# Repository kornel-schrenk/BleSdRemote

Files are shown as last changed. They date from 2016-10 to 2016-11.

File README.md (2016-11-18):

# BleSdRemote

For more information please see this blog [post](http://www.schrenk.hu/2016/11/17/BleSdRemote/)!

## Description

Nowadays some high end phones do not have an extra SD card slot, therefore its users are limited to the  internal storage space of the device. If you need more, you have to spend more money or use the manufacturer's proprietary cloud solution as an alternative extension.

Is there a way to solve this problem? I hope so! Only some *extra* storage space has to be *attached* to these mobile phones.

However this attachment can be problematic! Fortunately [Bluetooth Low Energy](https://en.wikipedia.org/wiki/Bluetooth_low_energy) (BLE) is supported by today's all major mobile phone operating systems: iOS, Android and Windows Phone. The idea is to add extra storage space to these mobile phones through BLE, which *demonstrates* that this extension is **possible**!

The solution consist of two parts:
1. An external SD card extension, which is driven by an [Arduino](http://www.arduino.org/) microcontroller.
2. An [Android](https://www.android.com/) application, which provides access to the remote SD card content.

The repository contains the [Arduino](http://www.arduino.org/) code. The related [Android](https://www.android.com/) code can be found in the [BleSdRemoteDroid](https://github.com/kornel-schrenk/BleSdRemoteDroid) GitHub repository.

## Breadboard view

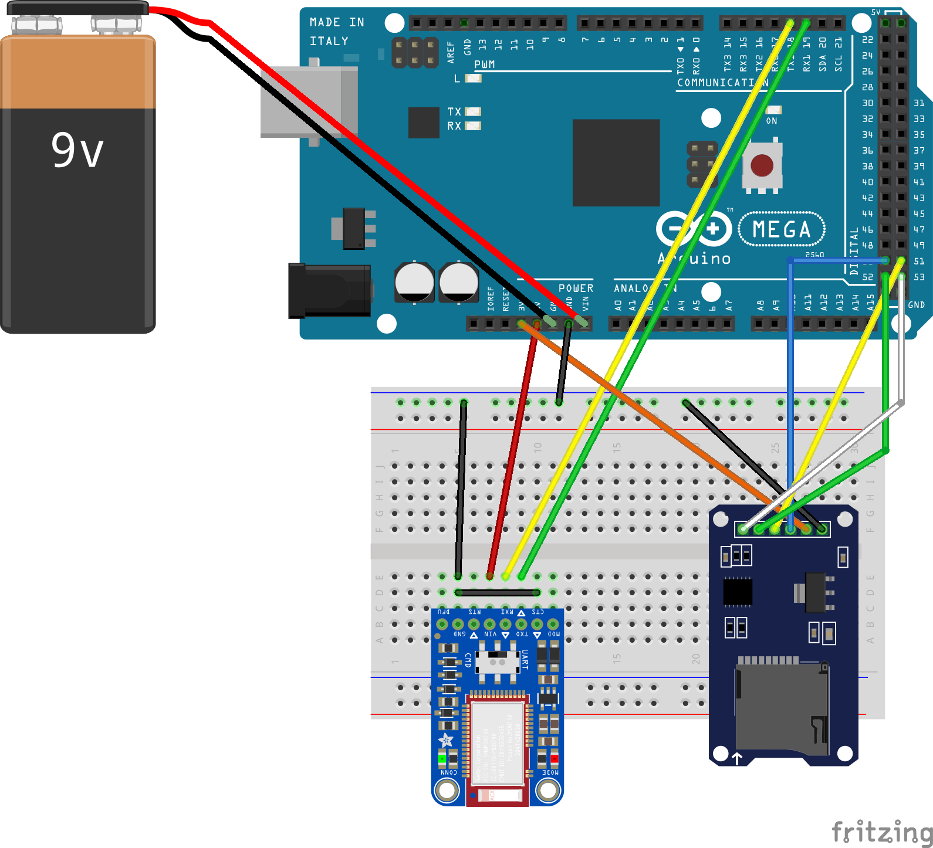
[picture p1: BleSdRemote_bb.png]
Fritzing breadboard view


## Communication API

```javascript
IN  <-: @LIST# - List all files and directories in the root folder
OUT ->: @DIVE0001.TXT,DIVE0002.TXT,DIVE0003.TXT,LOGBOOK.TXT,BOOKS/,PICTURES/,#

IN  <-: @LIST:BOOKS# - List all files and directories in the given folder
OUT ->: @../,TEST.JPG,TUSKEVAR.PDF,BAROK.PDF,#

IN  <-: @INFO:Images/About.png# - Sends back information about the given file
OUT ->: @<file name>%<file size in bytes>%<file creation date>%<file modification date>#

IN  <-: @DELF:Images/About.png# - Deletes the given file on the SD card
OUT ->: @OK%<file path># or @KO%<file path>#

IN  <-: @GETF:Images/About.png# - Download the given file from the SD card
OUT ->: @<file size in bytes>#<file content>

IN  <-: @PUTF:Images/About.png%<file size in bytes># - Upload the given file to the SD card
OUT ->: @OK# -> Switch Arduino into file receiving mode
IN  <-: <file content>
```

Every inbound message starts with the **@** character and ends with a **#**. The **:** divides the message into two parts; the keyword and the payload part. Outbound messages are similar to the inbound messages except that the delimiter character is the **%**.

## Repository Owner 

* [Kornel Schrenk](http://www.schrenk.hu/about/)

## License

This software is available under [MIT](../master/LICENSE) license.

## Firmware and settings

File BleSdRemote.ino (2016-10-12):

#include "Arduino.h"
#include "SPI.h"
#include "SdFat.h"

#include "Adafruit_BLE.h"
#include "Adafruit_BluefruitLE_SPI.h"
#include "Adafruit_BluefruitLE_UART.h"

#include "BluefruitConfig.h"

//Please set it to 1, if factory reset is desired during startup otherwise set it to 0
#define FACTORYRESET_ENABLE 0

#if defined(HAVE_HWSERIAL1) //Use the first physical serial UART on Arduino Mega or Due
Adafruit_BluefruitLE_UART ble(Serial1, BLUEFRUIT_UART_MODE_PIN);
#else //Use Software Serial interface -- Do not forget to adjust the configuration!!!
SoftwareSerial bluefruitSS = SoftwareSerial(BLUEFRUIT_SWUART_TXD_PIN, BLUEFRUIT_SWUART_RXD_PIN);
Adafruit_BluefruitLE_UART ble(bluefruitSS, BLUEFRUIT_UART_MODE_PIN, BLUEFRUIT_UART_CTS_PIN, BLUEFRUIT_UART_RTS_PIN);
#endif

const int ledPin = 13;  // led pin
const int sdChipSelectPin = 53; //For Mega TFT LCD shield use 53, for SD card reader use 10

SdFat SD;

//Message handling related variables 
String messageBuffer = "";
bool recordMessage = false;

bool storeInFileMode = false;
unsigned long storeFileSize = 0;
unsigned long receivedFileSize = 0;
SdFile storeFile;

void setup() {
	Serial.begin(115200);

	while (!Serial) { // Wait for USB Serial
		SysCall::yield();
	}
	delay(1000);

	Serial.println(F("\nBlueSdRemote - START\n"));

	Serial.print(F("SD - Initializing SD card..."));
	pinMode(sdChipSelectPin, OUTPUT);
	if (!SD.begin(sdChipSelectPin, SPI_HALF_SPEED)) {
		//Stop the sketch execution
		SD.initErrorHalt();
	} else {
		Serial.println(F(" Done."));
	}

	/* Initialise the module */
	Serial.print(F("BLE - Initializing the Bluefruit LE module: "));

	if (!ble.begin(VERBOSE_MODE)) {
		Serial.println(F("Couldn't find Bluefruit, make sure it's in CoMmanD mode & check wiring?"));
	}
	Serial.println(F("OK!"));

	if (FACTORYRESET_ENABLE) {
		/* Perform a factory reset to make sure everything is in a known state */
		Serial.println(F("BLE - Performing a factory reset: "));
		if (!ble.factoryReset()) {
			Serial.println(F("Couldn't do factory reset"));
		} else {
			Serial.println(F("OK!"));
		}
	}

	ble.echo(false);
	ble.info();
	ble.verbose(false);

	/* Wait for connection - Adafruit Bluefruit LE app has to be used to establish an UART connection. */
	while (!ble.isConnected()) {
		delay(500);
	}

	// Set module to DATA mode
	ble.setMode(BLUEFRUIT_MODE_DATA);
	Serial.println(F("BLE - Switched to DATA mode!"));
}

void loop() {

	//Read messages from the standard Serial interface
	if (Serial.available() > 0) {
		readMessageFromSerial(Serial.read());
	}

	//Read messages from the BLE interface
	while (ble.available()) {
		readMessageFromSerial((char) ble.read());
	}
}

void readMessageFromSerial(char data) {
	if (!storeInFileMode) {
		if (data == '@') {
			messageBuffer = "";
			recordMessage = true;
			digitalWrite(ledPin, HIGH); //Turn the LED on
		} else if (data == '#') {
			handleMessage(messageBuffer);
			recordMessage = false;
			digitalWrite(ledPin, LOW); //Turn the LED off
		} else {
			if (recordMessage) {
				messageBuffer += data;
			}
		}
	} else {
		if (receivedFileSize < storeFileSize && storeFile.isOpen()) {
			storeFile.write(data);
			receivedFileSize++;
		} else if (receivedFileSize == storeFileSize) {
			storeFile.flush();
			storeFile.close();

			Serial.print(receivedFileSize);
			Serial.print("/");
			Serial.println(storeFileSize);
			Serial.flush();

			Serial.println(F("Switched back into normal message processing mode!"));

			messageBuffer = "";
			storeInFileMode = false;
		}

		if (receivedFileSize % 512 == 0) {
			storeFile.flush();

			Serial.print(receivedFileSize);
			Serial.print("/");
			Serial.println(storeFileSize);
			Serial.flush();
		}
	}
}

void handleMessage(String message) {
	Serial.println(message);
	Serial.flush();

	String responseMessage = "";
	if (message.startsWith(F("LIST:")) || message.startsWith(F("list:"))) {

		//The String has to be converted into a char array, otherwise the board will reset itself
		String directoryPath = extractDirectoryPath(message);
		char directoryPathArray[directoryPath.length()+1];
		directoryPath.toCharArray(directoryPathArray, directoryPath.length()+1);

		if (SD.chdir(directoryPathArray)) {
			responseMessage += listDirectory(SD.vwd(), false);
			SD.chdir(); //Change back to the ROOT directory
		} else {
			Serial.print(F("Failed to open "));
			Serial.println(directoryPathArray);
			responseMessage += F("ERROR");
		}
		Serial.println(responseMessage);
		Serial.flush();
		ble.print(responseMessage);
		ble.flush();
	} else if (message.startsWith(F("LIST")) || message.startsWith(F("list"))) {
		//Change back to the ROOT directory
		if (SD.chdir()) {
			responseMessage += listDirectory(SD.vwd(), true);
		} else {
			responseMessage += F("ERROR");
		}
		Serial.println(responseMessage);
		Serial.flush();
		ble.print(responseMessage);
		ble.flush();
	} else if (message.startsWith(F("INFO:")) || message.startsWith(F("info:"))) {

		//The String has to be converted into a char array, otherwise the board will reset itself
		String directoryPath = extractDirectoryPath(message);
		char directoryPathArray[directoryPath.length()+1];
		directoryPath.toCharArray(directoryPathArray, directoryPath.length()+1);

		SdFile currentFile;
		if (currentFile.open(directoryPathArray, O_READ)) {
			Serial.print("@");
			currentFile.printName(&Serial);
			Serial.print("%");
			Serial.print(currentFile.fileSize());
			Serial.print("%");
			currentFile.printCreateDateTime(&Serial);
			Serial.print("%");
			currentFile.printModifyDateTime(&Serial);
			Serial.println("#");
			Serial.flush();

			ble.print("@");
			currentFile.printName(&ble);
			ble.print("%");
			ble.print(currentFile.fileSize());
			ble.print("%");
			currentFile.printCreateDateTime(&ble);
			ble.print("%");
			currentFile.printModifyDateTime(&ble);
			ble.print("#");
			ble.flush();
		}

	} else if (message.startsWith(F("GETF:")) || message.startsWith(F("getf:"))) {

		//The String has to be converted into a char array, otherwise the board will reset itself
		String directoryPath = extractDirectoryPath(message);
		char directoryPathArray[directoryPath.length()+1];
		directoryPath.toCharArray(directoryPathArray, directoryPath.length()+1);

		SdFile currentFile;
		if (currentFile.open(directoryPathArray, O_READ)) {
			dumpFile(&currentFile, &ble, currentFile.fileSize());
			currentFile.close();
		}
	} else if (message.startsWith(F("DELF:")) || message.startsWith(F("delf:"))) {

		//The String has to be converted into a char array, otherwise the board will reset itself
		String directoryPath = extractDirectoryPath(message);
		char directoryPathArray[directoryPath.length()+1];
		directoryPath.toCharArray(directoryPathArray, directoryPath.length()+1);

		if (SD.remove(directoryPathArray)) {
			Serial.print(F("@OK%"));
			Serial.print(directoryPath);
			Serial.print("#");
			Serial.flush();
			ble.print(F("@OK%"));
			ble.print(directoryPath);
			ble.print("#");
			ble.flush();
		} else {
			Serial.print(F("@KO%"));
			Serial.print(directoryPath);
			Serial.print("#");
			Serial.flush();
			ble.print(F("@KO%"));
			ble.print(directoryPath);
			ble.print("#");
			ble.flush();
		}
	} else if (message.startsWith(F("PUTF:")) || message.startsWith(F("putf:"))) {

		//The String has to be converted into a char array, otherwise the board will reset itself
		String directoryPath = extractUploadPath(message);
		char directoryPathArray[directoryPath.length()+1];
		directoryPath.toCharArray(directoryPathArray, directoryPath.length()+1);

		if (SD.exists(directoryPathArray)) {
			SD.remove(directoryPathArray);
			Serial.println(F("Existing file was removed."));
		}

		if (storeFile.open(directoryPathArray, O_WRITE | O_CREAT | O_APPEND)) {
			storeFileSize = extractFileSize(message);
			receivedFileSize = 0;

			Serial.println(F("@OK#"));
			Serial.flush();
			ble.print(F("@OK#"));
			ble.flush();

			storeInFileMode = true;
			Serial.println(F("Switched into file STORAGE mode!"));
		} else {
			Serial.println(F("@KO#"));
			Serial.flush();
			ble.print(F("@KO#"));
			ble.flush();

			storeInFileMode = false;
		}
	}
}

void dumpFile(SdFile* currentFile, Adafruit_BluefruitLE_UART* out, uint32_t totalSize) {

	ble.print("@");
	ble.print(totalSize);
	ble.print("#");

	Serial.print(F("File size: "));
	Serial.print(totalSize);
	Serial.println(F(" bytes"));

	unsigned long readSize = 0;
	byte buffer[1024];
	int readBytes;
	while (true) {
		readBytes = currentFile->read(buffer, sizeof(buffer));
		readSize += readBytes;
		if (readBytes == -1) {
			Serial.println(F("File read error."));
			return;
		} else if (readBytes < 1024) {
			out->write(buffer, readBytes);
			out->flush();
			Serial.print(readSize);
			Serial.print("/");
			Serial.println(totalSize);
			Serial.println(F("GETF completed."));
			return;
		} else {
			out->write(buffer, readBytes);
			out->flush();
			Serial.print(readSize);
			Serial.print("/");
			Serial.println(totalSize);
			delay(500); //Delay was added to switch the line back into normal state
		}
	}
}

String extractDirectoryPath(String message) {
	String directoryPath = message.substring(5, message.length());
	Serial.print(F("File path: "));
	Serial.println(directoryPath);
	return directoryPath;
}

String extractUploadPath(String message) {
	String directoryPath = message.substring(5, message.indexOf('%'));
	Serial.print(F("Upload path: "));
	Serial.println(directoryPath);
	return directoryPath;
}

unsigned long extractFileSize(String message) {
	String fileSize = message.substring(message.indexOf('%')+1);
	Serial.print(F("Upload file size: "));
	Serial.println(fileSize);
	return fileSize.toInt();
}

String listDirectory(FatFile* currentDir, bool isRoot) {
	//Start the reply with the @ sign
	String responseMessage = "@";

	if (!isRoot) {
		//Append the level up command
		responseMessage += "../,";
	}

	char longFileName[256];
	while (true) {
		SdFile currentFile;
		if (!currentFile.openNext(currentDir, O_READ)) {
			//No more files - close the message
			responseMessage += "#";
			return responseMessage;
		}
		currentFile.getName(longFileName, 256);
		responseMessage += longFileName;
		if (currentFile.isDir()) {
			responseMessage += "/";
		}
		responseMessage += ",";
		currentFile.close();
	}
}

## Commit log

2016-10-12 Upload related bug fixes.
    [BleSdRemote.ino]
2016-11-15 More description and Fritzing breadboard layout was added.
    [BleSdRemote.fzz]
